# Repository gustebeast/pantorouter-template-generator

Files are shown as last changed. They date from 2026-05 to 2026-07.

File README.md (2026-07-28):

# Pantorouter Template Generator

Browser-based parametric generator for [Pantorouter](https://pantorouter.com)
mortise/tenon templates. Pick units (mm or in), enter your tenon size, bit
diameter, and guide bushing diameter, hit Generate, and download STEP or
STL files for both the template body and its matching rail.

## Live tool

**[gustebeast.github.io/pantorouter-template-generator](https://gustebeast.github.io/pantorouter-template-generator/)**

The browser does all the geometry locally via
[replicad](https://replicad.xyz) (a JavaScript port of OpenCascade, the same
CAD kernel used by FreeCAD). After the kernel loads (~5 MB,
once-per-browser), nothing leaves your machine.

## Features

- **mm or inches** — toggle at the top of the form converts every input.
- **STEP or STL** — pick the format that matches your workflow. STL goes
  straight to your slicer; STEP opens in any CAD tool.
- **3D preview** — built-in three.js viewer with toggles to show / hide
  the body and rail independently. Left-click to rotate, right-click
  to pan, scroll to zoom.
- **Debossed label** in the mortise pocket showing the joint dimensions
  in the units you generated with — so you can identify a printed
  template at a glance.

## What it generates

- **`pantorouter-template-body`** — main piece. Has the dual
  mortise/tenon guide profiles, three pilot holes (drill out to 4 mm
  for screws, 6 mm for the center pin), and a dovetail slot in its
  back to receive the rail.
- **`pantorouter-template-rail`** — slides into the back of the body
  and engages the pantorouter's T-track. Prints separately to avoid
  needing structural support.
- **`pantorouter-template-assembled-demo`** — both pieces in their
  as-mounted positions, fused into a single solid. Visual reference
  only — print the body and rail separately.

## Assembly

1. *(Optional)* Print the test mortise and tenon and check they fit
   together. You can also print the screw test to see how the two
   mounting holes will fit on your Pantorouter's T track.
2. Print the body and the rail. **Dual rail mount:** print two copies
   of the rail — one for each slot in the body.
3. Apply super glue to the rail (each rail, for dual rail mount).
4. Slide the rail into the body (one rail per slot for dual rail mount).
5. Wait for the glue to cure.
6. Use 4 mm and 6 mm drill bits to widen the pilot holes, drilling
   straight through the base plate AND the glued rails (rails print
   solid; the pocket floor's reference counterbores indicate which is
   which).

## Design

Based on "Pantorouter Tenon Template" by FozzTexx (CC0 1.0). Pantograph
math verified against The Pantorouter Co.'s sizing calculator. The
rail ↔ body joint is the cadkit octagon ("stop sign") slide joint —
ported from the vendored `cadkit/joinery.py` (the canonical geometry;
keep the port in sync). Both halves print flat with every face vertical
or 45°; the octagon width is solved so the cavity fits the base plate's
countersink stack. Rail clearance 0.25 mm. Rails print SOLID — no
printed holes; after glue-up, drill the center/screw holes straight
through the base plate and rail, guided by the body's printed pilots.

## Materials

Originally designed for **PA6-GF** with a 0.4 mm nozzle, but PLA, PETG,
ABS, ASA, and other common FDM filaments work too. Tunable shrink
compensation for material-specific calibration. Use a brim on the rail
(it's long and thin) for reliable bed adhesion.

## Examples

Pre-generated reference outputs at the default parameters
(20 × 70 mm tenon, 12.7 mm bit, 12 mm bushing) live in
**(STALE since the octagon-joint change — regenerate in the browser)**
[`example/`](example/):

- `pantorouter-template-body.step`
- `pantorouter-template-rail.step`
- `pantorouter-template-assembled-demo.step` — both pieces in their
  as-mounted positions, for visual verification only.

To regenerate after a geometry change: open the live tool at default
parameters, click Generate, save the three STEP files into `example/`,
and copy the assembled demo over the root `assembly.step` (what
`View Assembly.cmd` opens in the FreeCAD viewer hub).

## Local development

The site is plain static HTML/JS; no build step. To preview locally:

```sh
python3 -m http.server 8080
# open http://localhost:8080
```

(A real HTTP server is needed; `file://` won't work for the WASM
imports replicad does on first load.)

## Authorship

The CAD geometry, web UI, and three.js preview were written entirely by
[Claude](https://claude.ai) (Anthropic) over a long pair-programming
session. Original SCAD design (which this is parametrically derived from)
is by FozzTexx.

## License

CC0 (matching FozzTexx's original).

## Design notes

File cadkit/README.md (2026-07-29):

# cadkit

Small, project-agnostic helpers for **parametric 3D-printing with CadQuery** — the
shared code behind a set of printable-hardware projects. Vendored into each project via
`git subtree`, so every project repo stays self-contained.

## Layout

```
cadkit/
  fasteners.py       M2/M4 hole + heat-set-insert geometry (self-tap now, insert later);
                     one FastenerSpec API, print-undersize aware
  threads.py         self-supporting 45° FDM screw threads (read THREADS_README.md first)
  joinery.py         printable mortise-and-tenon slide joints (read JOINERY_README.md)
  supports.py        teardrop + 45° wall-ramp support for short SIDEWAYS bosses
                     (horizontal cylinder off a wall, printed -Z→+Z)
  holes.py           teardrop_hole() — cutter for SIDEWAYS round holes: 45°
                     teardrop ceiling replaces the sagging round top; round
                     lower half untouched (pins/rods bear as in a round bore)
  contact.py         minimal-contact rub features: contact_rib_size(nozzle)
                     = exactly one nozzle (width AND proud; Arachne keeps
                     exact-nozzle lines); contact_ring() = ring + teardrop tail
  step_export.py     export_step(obj, path) — names the STEP product after the file
  overlap_check.py   parallel interpenetration gate (wrap in tools/check_overlaps.py)
  cq_colors.py       hex / 0..255 / name -> cq.Color, for baking colours into a STEP
  freecad/           OPTIONAL FreeCAD viewer hub (isolated so the core needs no FreeCAD)
    __init__.py        `from cadkit.freecad import show`
  tools/
    agent_sync.py    dev-only multi-agent git-worktree coordination CLI (run as a script)
```

The **core** modules depend only on CadQuery/OCP — no FreeCAD. The FreeCAD-specific
viewer lives in `cadkit.freecad` and is opt-in; `show()` never raises, so viewer trouble
can't break a build.

## Use

```python
from cadkit.fasteners import cut_anchor, M2, M4
from cadkit.threads import cut_thread, threaded_rod
from cadkit.joinery import arrow_tenon, arrow_mortise
from cadkit.step_export import export_step
from cadkit.overlap_check import run
from cadkit import cq_colors
from cadkit.freecad import show          # optional; opens/refreshes a FreeCAD viewer tab
```

A project vendors cadkit at its repo root and runs its build via `python -m` from there,
so `cadkit` is importable with no path hack.

## Vendoring into a project

```
git remote add cadkit https://github.com/gustebeast/cadkit
git subtree add  --prefix=cadkit cadkit main --squash    # first time
git subtree pull --prefix=cadkit cadkit main --squash    # to update later
```

## Changing cadkit — you MUST propagate to every consumer

cadkit is **vendored** (copied) into each project, so the copies **drift** the
moment the canonical repo changes — nothing forces them identical. Therefore a
cadkit change is not *done* when you commit it; it is done when every consumer
project has been re-pulled. **Never edit a project's vendored `cadkit/` in place** —
edit the canonical repo, then propagate.

The whole process is one command — **run it from the standalone canonical cadkit
checkout, after committing your change there** (it refuses to run from a project's
vendored copy):

```
py -3.12 tools/propagate.py        # pushes canonical, then re-pulls into every consumer
```

It pushes the canonical to its upstream (one source of truth), auto-discovers
every sibling project that vendors cadkit, and re-pulls the subtree into each.
A project with a **dirty** working tree is **skipped** (never auto-stashed) and
reported — commit or stash there, then re-run. The exit code is the number of
consumers *not* in sync, so `propagate.py` doubles as a gate: **0 means every
project is current.** Use `--dry-run` to preview, `--no-push` to pull only.

(The manual equivalent, per project, is `git fetch cadkit main &&
git subtree pull --prefix=cadkit cadkit main --squash` — but do not hand-run it
across N repos; that is exactly the step people forget, which is what drift is.)

See `THREADS_README.md` and `JOINERY_README.md` before changing threads or joinery —
both encode FDM-specific rules that fail silently if broken.

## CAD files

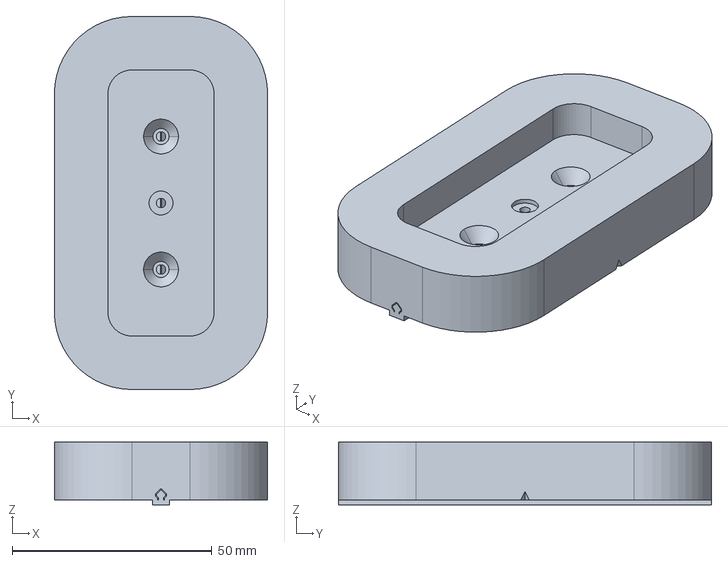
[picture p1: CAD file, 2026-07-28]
example/pantorouter-template-assembled-demo.step
53.4 x 93.4 x 15.8 mm

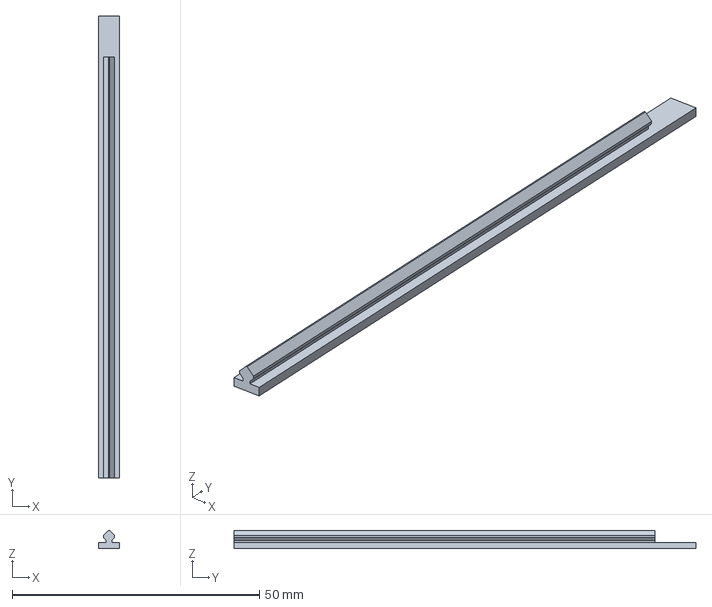
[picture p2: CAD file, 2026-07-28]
example/pantorouter-template-rail.step
4.20 x 93.4 x 3.73 mm

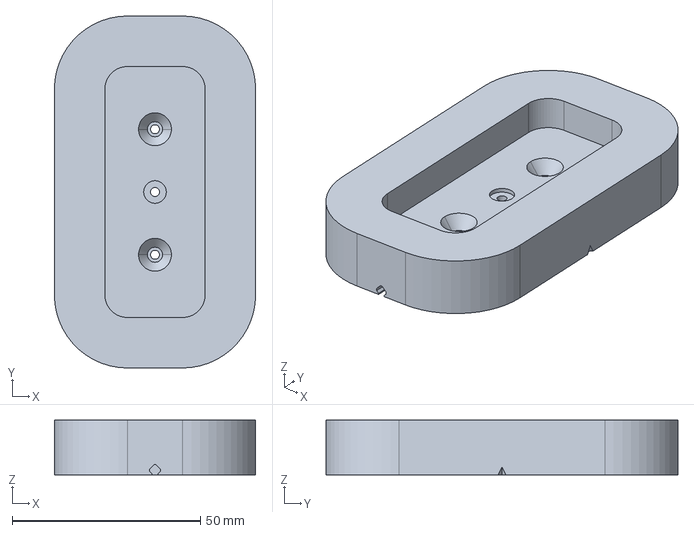
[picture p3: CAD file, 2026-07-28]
example/pantorouter-template-body.step
53.4 x 93.4 x 14.5 mm

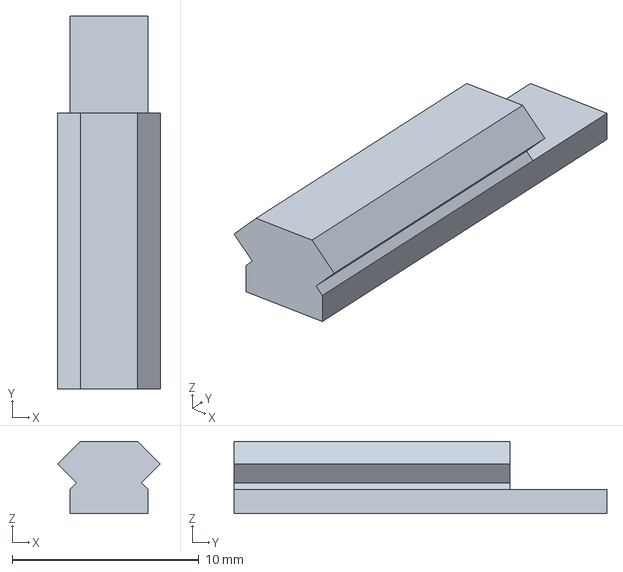
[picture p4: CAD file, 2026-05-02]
example/pantorouter-template-tenon-test.step
5.50 x 20.0 x 3.87 mm

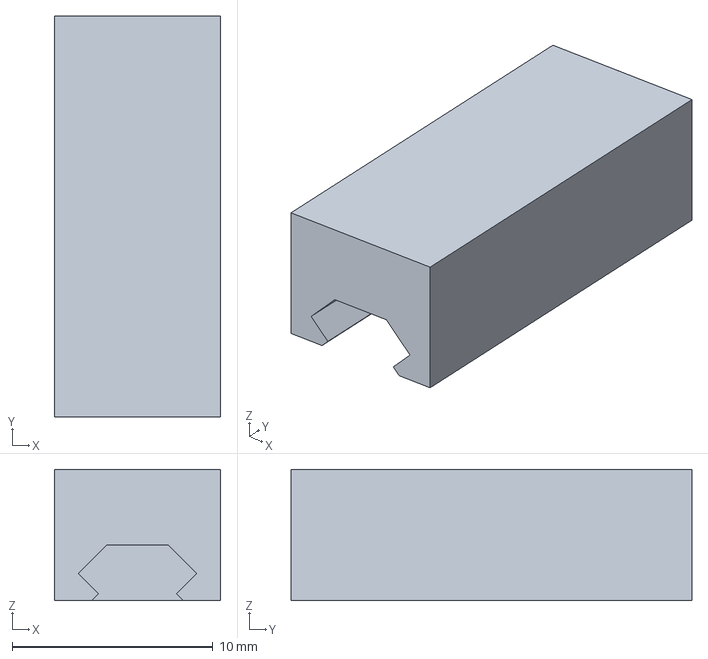
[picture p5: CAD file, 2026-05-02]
example/pantorouter-template-mortise-test.step
8.30 x 20.0 x 6.55 mm

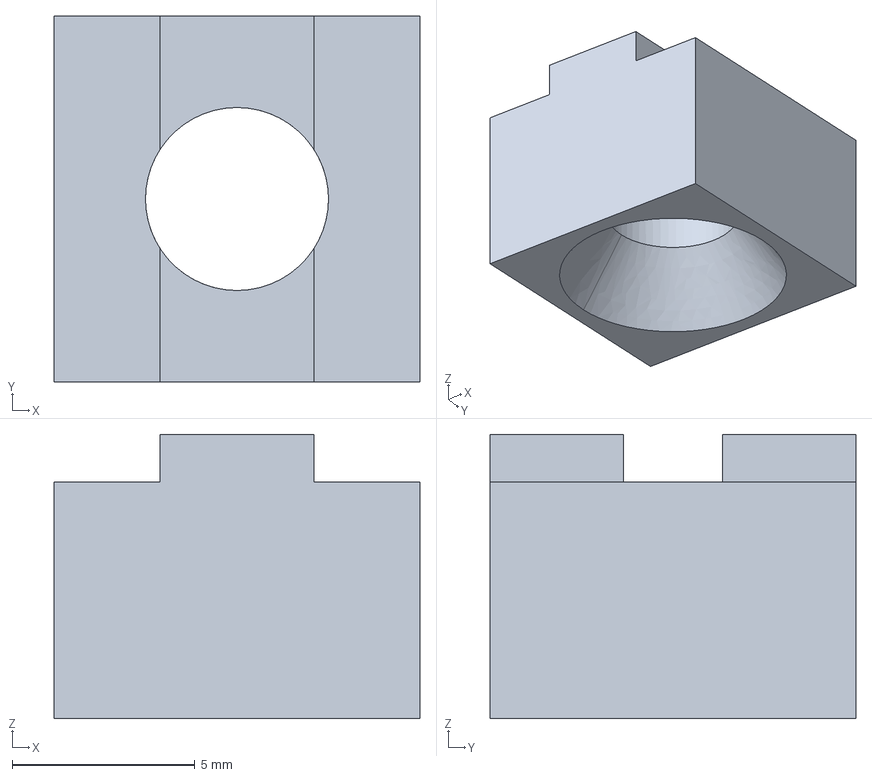
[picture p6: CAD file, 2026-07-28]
example/pantorouter-template-screw-test.step
10.0 x 10.0 x 7.76 mm

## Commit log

2026-04-30 Drop test/flat pieces from web version
    The test mortise/tenon and flat clearance wafers were design-iteration
    tooling. Now that the dovetail clearance is dialed in (RAIL_CLEARANCE
    = 0.2 mm), end users only need the body and the rail.
2026-04-30 Add 3D preview canvas + dark-mode theme
    - Three.js scene below the parameters; renders body + rail in their
    assembled positions after each Generate. Drag to orbit, scroll to
    zoom. Color-coded: body gray, rail orange.
    - Switched UI to dark theme.
2026-04-30 Add show/hide checkboxes for body and rail in preview
    Each part's three.js objects (mesh + edges) are now tracked separately
    under previewParts.body / previewParts.rail. The two checkboxes below
    the canvas toggle each set's visibility independently, so the user can
    inspect either piece in isolation.
2026-04-30 Fix preview toggles + dark-blue theme + remove broken FozzTexx link
    - Renamed initPreview's local 'key' (DirectionalLight) to 'keyLight'
    to avoid shadowing the for-of iterator and confusing the closure on
    some engines.
    - Refactored toggle handlers to a shared setPartVisibility() helper,
    plus listen on both 'change' and 'input' for max event coverage.
    - Console.warn if a checkbox isn't found at boot.
    - Theme accent: orange (#e0883a) -> dark-mode blue (#6ea8fe). Rail's
    preview color stays orange so it's distinguishable from the body.
    - The FozzTexx 'CC0 design' link pointed to printables.com homepage
    instead of the actual model — removed the link since I don't have
    the canonical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
2026-04-30 Add STEP/STL format selector above the Generate button
    New 'Output' fieldset with a select that defaults to STEP. Switching
    to STL re-renders the button label and produces .stl files via
    shape.blobSTL(). Filenames keep their pantorouter-template-{body,rail}
    stem with the extension swapped.
2026-04-30 Simplify button label to 'Generate files'
    Format choice is already obvious from the dropdown directly above —
    the button just runs whatever's selected. Bump asset cache version too.
2026-04-30 Update Files-section copy to mention both STL and STEP
    Now that the format selector lets users pick STL directly, the help
    text reflects both paths: STL straight into any slicer; STEP for CAD
    inspection.
2026-04-30 Drop .step extension from generated-files dl
    The format depends on the user's selection now — listing extensions
    in the help text is misleading when STL is chosen.
2026-04-30 Replace 'What gets generated' details with assembly instructions
    - Subtitle gains a sentence explaining why the rail prints separately
    (no structural support needed).
    - Removed the file-list <dl> in the details element.
    - Added an ordered Instructions list with 5 assembly steps:
    print, glue, slide, cure, drill out the pilots.
2026-04-30 Drop the Python reference files now that the web app is the source of truth
    - Delete pantorouter_template_generator.py (CadQuery reference) and
    run_pantorouter.command (macOS launcher).
    - Trim .gitignore: remove Python-specific entries and stale STEP/STL
    globs (those test files lived in the repo root during the Python
    era; web app downloads via the browser, never to disk).
    - Drop the misleading printables.com homepage link from the README.
2026-04-30 Drop 'Tenon' prefix from input labels
    Mortise and tenon end up at the same nominal dimensions in a
    Pantorouter joint, so the prefix is misleading. Fieldset legend
    'Tenon / Mortise' already conveys what's being sized.
    [pantorouter-template-body-sample.step, pantorouter-template-rail-sample.step]
2026-04-30 Remove accidentally-committed sample STEP files; ignore generated outputs
    Two pantorouter-template-*-sample.step files slipped into the previous
    commit because I had stripped the *.step / *.stl globs from .gitignore
    when cleaning up Python-era entries. Restoring those globs so any
    local generation downloads land in .gitignore.
    [pantorouter-template-body-sample.step, pantorouter-template-rail-sample.step]
2026-04-30 Add mm/inch unit toggle and debossed dimension label
    Units:
    - New 'Units' fieldset at the top of the form with mm/in radios.
    - Switching converts every dimensional input value (tenon W/L/radius,
    bit, bearing, template depth) and updates the label suffixes via the
    .unit-label spans. Step size also flips to 0.1 mm or 0.001 in.
    - generateAll converts back to mm before passing to deriveSizes — the
    geometry is always built in mm internally.
    Debossed label:
    - New debossLabelOnPocketFloor() cuts a 1 mm-deep deboss into the
    pocket floor (visible from above looking into the pocket) showing
    the joint dimensions in the user's chosen unit, e.g. '20 x 70 mm'
    or '0.787 x 2.756 in'.
    - Font s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
2026-04-30 Slim the rail to fit a 4.3 mm T-track
    Three changes:
    - RAIL_LEAD_IN_LEN: 0.8 -> 0.495 mm. This sets the rail's bottom
    width (where dovetail meets the rectangular base) to exactly
    4.3 mm at the current 0.2 mm per-side clearance:
    rail_bottom = NECK_W + 2*LEAD_IN_DX - 2*c
    = 4 + 2*0.35 - 0.4 = 4.3 mm
    Slot opening shrinks correspondingly to 4.7 mm.
    - RAIL_TOP_FLAT: 1.2 -> 1.169 mm.
    - RAIL_BASE_W: 8.0 -> 4.3 mm so the rectangular base lines up
    with where the 45 deg cuts terminate at z=0.
2026-04-30 Flatten docs/ to repo root + add example/ folder with sample STEPs
    - index.html / main.js / style.css now live at the repo root.
    - GitHub Pages source switched from /docs to / via the gh API.
    - New example/ holds three reference STEPs at the default parameters
    (20 x 70 mm tenon, 12.7 mm bit, 12 mm bushing): body, rail, and an
    assembly view showing both pieces in place.
    - .gitignore globally ignores *.step / *.stl but explicitly whitelists
    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
    [pantorouter-template-assembled.step, pantorouter-template-body.step, pantorouter-template-rail.step]
2026-04-30 Add pantorouter-template-assembled.{step,stl} to web outputs
    New buildAssembly(d) fuses the body and rail in their as-mounted
    positions and emits a third file. The fused result is for
    visualization only — print the body and rail separately and slide
    them together. The 3D preview already renders body+rail so the
    assembled piece skips the preview pass to avoid double-rendering.
2026-04-30 Drop pocket-floor height by 1 mm via wider tip
    RAIL_TOP_FLAT 1.169 -> 3.169 mm shortens the upper 45 deg walls by
    1 mm vertical (and horizontal) while keeping the catch width and
    slope unchanged. Net effect:
    RAIL_TIP_H: 3.766 -> 2.766 mm
    SLOT_DEPTH: 3.766 -> 2.766 mm
    BASE_DEPTH: 4.766 -> 3.766 mm (pocket floor is the bearing surface)
    rail bottom width: 4.300 mm (unchanged)
    catch width: 6.000 mm (unchanged)
    The 1 mm buffer between slot peak and pocket floor is preserved
    (BASE_DEPTH = SLOT_DEPTH + 1).
2026-04-30 Widen pilot holes from 1 mm to 3.169 mm
    Matches RAIL_TOP_FLAT exactly: the pilot now spans the full flat
    width of the dovetail tip. Less material to drill out post-print on
    the way to final 4 mm (screws) and 6 mm (center pin) sizes. The
    reference counterbores at the pocket floor still indicate the target
    diameters.
    [pantorouter-template-assembled.step]
2026-04-30 Bump tip flat + pilot to 4 mm (matches M4 clearance)
    - RAIL_TOP_FLAT: 3.169 -> 4.0 mm
    - PILOT_DIA: 3.169 -> 4.0 mm
    Side effects:
    - RAIL_TIP_H: 2.766 -> 2.350 mm (tenon shortens by 0.416 mm)
    - BASE_DEPTH: 3.766 -> 3.350 mm (pocket floor drops correspondingly)
    - Pilot now equals M4 clearance dia, so the screw holes can be used
    as-printed without drilling out — though for a true free-clearance
    fit M4 typically wants 4.3 mm. Center-pin reference (6 mm) still
    needs drilling. Pilot fully spans the tip flat at the screw
    positions, so there's no flat material around those pilots; the
    flat between the pilots is intact.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
2026-04-30 Revert tip flat + pilot back to 3.169 mm
    The 4 mm value would break out of the rail's shoulder (NECK_W − 2c
    = 3.6 mm narrowest cross-section above the base), since the pilot
    can't be wider than the surrounding material at any height.
    Back to TOP_FLAT = PILOT_DIA = 3.169 mm — well under the 3.6 mm
    ceiling. M4 clearance still requires post-print drilling, but that
    matches the existing reference-counterbore workflow.
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2026-04-30 Revert pilot back to 3.169 mm (full tip-flat width)
    Try the slicer without the 0.4 mm wall around each pilot — the
    pilot fully spans the tip flat at the screw locations again. If
    it prints fine without the buffer, this saves a tiny bit of
    post-print drilling.
    [pantorouter-template-assembled.step, pantorouter-template-body.step, pantorouter-template-rail.step]
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2026-05-01 Slim rail base from 1.8 mm to 1.4 mm
    Less material below the template = lower overall stack height once
    the body and rail are mated.
    [pantorouter-template-assembled.step, pantorouter-template-body.step, pantorouter-template-rail.step]
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2026-05-01 Add pantorouter-template-screw-test sample piece
    10 x 10 mm vertical column carved from the assembled body+rail
    (built without clearance, so the dovetail joint is a single
    continuous solid as if perfectly glued), centered on one of the
    side screw holes. Hole is pre-drilled to 4 mm with the countersink
    cone in place — print and confirm a flat-head M4 sits flush and
    threads cleanly into your T-track without going through any
    printability headaches first.
2026-05-01 Slim countersink floor buffer from 1 mm to 0.4 mm
    COUNTERSINK_FLOOR_THICK: 1.0 -> 0.4 mm. Below each side hole's
    countersink cone there's now a 0.4 mm-tall cylindrical pilot region
    before the dovetail slot ceiling, instead of 1 mm. BASE_DEPTH drops
    from 7.149 to 6.549 mm — body floor is correspondingly thinner.
    Applies to the screw-test piece as well since it derives from the
    same constants.
    [pantorouter-template-assembled.step, pantorouter-template-body.step, pantorouter-template-rail.step]
2026-05-01 Slim rail base 4.3 -> 4.1 mm + tip flat 3.169 -> 2.969 mm
    T-track was just slightly tight; shaving 0.2 mm off the rail's
    rectangular base (RAIL_BASE_W) loosens the fit. Reducing TOP_FLAT
    by the same amount eats 0.1 mm into the wall around each pilot —
    PILOT_DIA stays 2.369 mm so the wall around the pilot at the tip
    flat goes from 0.4 mm to 0.3 mm per side, still solidly above the
    nozzle width.
    Note: the dovetail bottom at z=0 is still 4.3 mm wide (driven by
    LEAD_IN_LEN, not TOP_FLAT), so the dovetail now overhangs the base
    by 0.1 mm per side at the z=0 transition. If the overhang prints
    weird or you want the bottoms truly matched at 4.1, lower
    LEAD_IN_LEN from 0.495 to 0.354 mm to bring t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
    [pantorouter-template-assembled.step, pantorouter-template-body.step, pantorouter-template-rail.step]
2026-05-01 Uniform inward shrink: NECK_W 4.0->3.8, CATCH_W 6.0->5.8
    Combined with the previous TOP_FLAT 3.169->2.969 and RAIL_BASE_W
    4.3->4.1 changes, this is a coordinated 0.2 mm width reduction at
    every level of the dovetail. The 45 deg wall slopes are preserved
    (differences between adjacent widths are unchanged), so the heights
    SHOULDER_Z, UPPER_CATCH_H, TIP_H, BASE_DEPTH all stay the same.
    Slot widths: opening 4.7->4.5, shoulder 4.0->3.8, catch 6.0->5.8
    Rail widths: bottom 4.3->4.1, shoulder 3.6->3.4, catch 5.6->5.4
    Fit clearance is preserved (slot is 0.4 mm wider than rail at every
    level, same as before).
    [pantorouter-template-assembled.step, pantorouter-template-body.step, pantorouter-template-rail.step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]
2026-05-01 Add mortise-test + tenon-test fit-check pieces back to the web app
    Two ~20 mm joint mockups, parametric to the current dovetail/slot
    geometry:
    - pantorouter-template-mortise-test: 8.2 x 20 mm block (CATCH_W +
    2*1.2 mm wall) with the slot cut into it (10 mm slot length +
    10 mm closed cap).
    - pantorouter-template-tenon-test: matching 4.1 x 1.3 mm base x
    20 mm rail, with the dovetail offset toward one end so it butts
    the cap when the base is flush.
    These give a quick way to validate the slot/rail clearance before
    printing the full template body. Same uniform inward shrink as the
    main parts (NECK_W=3.8, CATCH_W=5.8) so they reflect current geometry.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
    [pantorouter-template-assembled.step, pantorouter-template-body.step, pantorouter-template-rail.step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]
2026-05-01 Flip the screw-test piece so it prints pocket-floor-down
    The screw test isn't trying to validate slot/rail printability —
    it's just verifying the M4 + countersink + T-track interface. In
    the natural (pocket-up) orientation, the rail-base-to-body
    transition at z=0 demands a 2.95 mm bridge per side because the
    body section (10x10 mm) is wider than the rail base (4.1 mm) at
    that height. Flipping the piece 180 deg around Y inverts that —
    the bed contacts the wide pocket-floor side, the cross-section
    narrows monotonically going up, and no bridge is needed.
    The other test pieces (mortise-test, tenon-test) intentionally
    stay in their natural orientation so the print validates the
    slot and rail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
    [pantorouter-template-mortise-test.step, pantorouter-template-tenon-test.step]
2026-05-01 Add Dual Rail Mount option for engaging all 3 T-tracks
    New checkbox in a 'Mounting' fieldset. When checked, the side screw
    holes shift from along the long axis (current behavior) to ±20 mm
    perpendicular to it, so:
    • Center hole engages the center T-track
    • Side holes engage the outer two T-tracks (±20 mm spacing)
    Useful for tall narrow templates where engaging all three tracks
    adds rotational stability vs a single rail.
    Constants:
    T_TRACK_SPACING = 20.0 mm
    COUNTERSINK_EDGE_BUFFER = 1.0 mm
    DUAL_RAIL_MIN_OUTER_W = 50.7 mm
    (= 2*spacing + cone_top_dia + 2*buffer)
    The checkbox is automatically disabled (and unchecked) when the
    template's short-axis width is < DUAL_R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
2026-05-01 Restore RAIL_BASE_W to 4.3 mm (was 4.1) — undo the T-track shrink
    Per print test, 4.1 mm sits loose in the track. Bumping it back to
    the original 4.3 mm — the 0.2 mm reduction we applied earlier was
    over-corrected. Dovetail dimensions (NECK_W, CATCH_W, TOP_FLAT)
    left at their shrunk values since the slot/rail fit hasn't been
    reported off — but note that this means the dovetail bottom (at
    z=0) is now 4.1 mm while the base (z=0+) is 4.3 mm, so the base
    overhangs the dovetail by 0.1 mm per side at z=0. Inward step from
    the print bed's perspective, no overhang to bridge.
2026-05-01 Uniform expansion to undo the earlier shrink — all four dims +0.2 mm
    Following the same all-or-nothing rule we set earlier: when changing
    the base for T-track fit, change every dimension proportionally so
    the dovetail walls stay parallel and the dovetail bottom matches the
    base width (no z=0 overhang).
    NECK_W: 3.8 -> 4.0
    CATCH_W: 5.8 -> 6.0
    TOP_FLAT: 2.969 -> 3.169
    BASE_W: 4.3 already
    Net: a full revert of the previous shrink. Slot opening 4.5 -> 4.7,
    dovetail bottom 4.1 -> 4.3 (matches base), shoulder 3.4 -> 3.6,
    catch 5.4 -> 5.6 (rail), 5.8 -> 6.0 (slot), tip 2.969 -> 3.169.
2026-05-01 Split the difference: uniform shrink of 0.1 mm (not 0.2)
    4.3 was too tight, 4.1 too loose. 0.1 mm uniform shrink keeps the
    geometry self-consistent (dovetail bottom = base) while landing
    between the two prior tries.
    NECK_W: 4.0 -> 3.9
    CATCH_W: 6.0 -> 5.9
    TOP_FLAT: 3.169 -> 3.069
    BASE_W: 4.3 -> 4.2
2026-05-01 Smaller cap on the fit-test pieces + over-drilled hole on the screw test
    - TEST_STOP_LEN: 10 mm -> 5 mm. Test mortise/tenon now has a 15 mm
    slide region instead of 10, with the same 20 mm total length —
    more room to feel the joint engage as the rail slides home.
    - Screw test drilled-through hole: 4 mm -> 5 mm (= SCREW_DIAMETER +
    1). Pretends someone over-drilled the pilot. If a flat-head M4
    still sits cleanly in this looser hole, the tighter as-printed
    final piece will too.
    [pantorouter-template-assembled.step, pantorouter-template-body.step, pantorouter-template-mortise-test.step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]
2026-05-01 Dual rail mount now actually adds the second slot
    Previously the checkbox only repositioned the screw holes — the
    body still had a single dovetail slot at x=0. Fixed:
    - New slotXPositions(d) returns [0] for single-rail and
    [-T_TRACK_SPACING, +T_TRACK_SPACING] for dual-rail.
    - buildTemplate cuts a slot at every position.
    - buildAssembly fuses a rail copy into every slot.
    - buildScrewTest cuts every slot and fuses a rail per slot before
    carving out the 10x10 column.
    - The preview's rail mesh is rendered at each slot position so the
    user sees both rails in dual-rail mode (the downloaded rail file
    is still a single piece — print it twice and slot one into each
    mortise).
    Co-Author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
    [pantorouter-template-assembled.step, pantorouter-template-body.step, pantorouter-template-mortise-test.step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]
2026-05-01 Fix dual-rail mount: both rails in assembly, floor-based feasibility
    - buildAssembly rebuilds a fresh rail per slot. The previous code
    reused a single rail across iterations, but .fuse() consumes its
    argument, so the second slot ended up empty.
    - Preview clones the THREE mesh per slot instead of re-translating
    the replicad shape (same use-after-free hazard).
    - Dual-rail checkbox is now gated on INNER_W / INNER_L (pocket floor),
    not OUTER_W. The cone bezels need to land on the floor with 1 mm
    clearance from the inner pocket wall, not just inside the body.
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2026-05-01 Tighten dual-rail step 1 wording
2026-05-01 Outer taper option, shorter centering notch, fix deboss font
    - New "Outer taper" checkbox: bottom of body is 2 mm wider and top is
    1 mm narrower than the nominal dimensions, lofted between the two
    profiles. Nominal sits at 2/3 of the way from wide to narrow so the
    bearing's adjustment range biases toward "make tenon bigger" (matches
    the OEM template design).
    - Centering V-notch is now only 2 mm tall at the top of the body so the
    bearing riding on the outer face below it doesn't snag.
    - Pocket-floor deboss now actually appears: replicad's font registry
    was empty, so drawText was silently returning nothing. Boot now loads
    JetBrains Mono as the default font. Also fixed a precedenc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
2026-05-02 Recommend printing test pieces before the full template
    [pantorouter-template-assembled.step, pantorouter-template-body.step, pantorouter-template-mortise-test.step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]
2026-05-02 Rename assembled file to assembled-demo
    [pantorouter-template-assembled-demo.step]
2026-07-28 rail joint: cadkit octagon slide joint; rails print solid (no holes)
    - slot/rail profiles swapped to the octagon (stop sign) joint ported
    from vendored cadkit/joinery.py; width solved (2.30 mm, cavity 2.68)
    to keep BASE_DEPTH's countersink stack; SLOT_DEPTH now derives from it
    - RAIL_CLEARANCE 0.2 -> 0.25
    - buildRail cuts no holes: drill through the glued stack after assembly,
    guided by the body's printed pilots
    - cache bump main.js?v=47; example STEPs marked stale pending browser
    regeneration
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2026-07-28 headless STEP generation: geometry.js split + Node runner
    - geometry layer extracted to geometry.js (UI-free factory), shared
    verbatim by the browser (main.js?v=48) and tools/generate.mjs, which
    runs npm replicad + the opencascade WASM under Node
    - example/ + sample-test STEPs regenerated with the octagon joint
    (validated in-kernel: octagon 2.30 mm, slot depth 2.68)
    - tools/make_assembly.py composes root assembly.step with body + rail
    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
    [pantorouter-template-assembled-demo.step, pantorouter-template-body.step, pantorouter-template-rail.step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]
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2026-07-29 Squashed 'cadkit/' changes from 366e905..99e6da6
    99e6da6 joinery: material/fit clearance policy - fiber-filled depth-face relief
    git-subtree-split: 99e6da6be60e51f358d659fc3afcaf6582a5f611
    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
